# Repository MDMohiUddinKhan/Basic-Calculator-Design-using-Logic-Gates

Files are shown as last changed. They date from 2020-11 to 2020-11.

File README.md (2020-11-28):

# Basic-Calculator-Design-using-Logic-Gates
I've designed Adder (4bit), Subtractor (4bit), Multiplier (2bit), Divisor (1bit) unit of basic BCD Calculator using Proteus Software; designed their PCB layout & had done Hardware Implementation.

# Adder-Subtractor unit:
UniConverter_20201128140115

# Multiplier unit:
UniConverter_20201128140604

# Divider unit:
UniConverter_20201128141047

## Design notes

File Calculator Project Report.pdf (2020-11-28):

# Islamic University of Technology (IUT)

## Organization of Islamic Cooperation (OIC)

## Department of Electrical and Electronic Engineering (EEE)

### Report Submission Date: 21st May, 2018

Course: EEE 4308 (Digital Electronics Lab)

Experiment Name: Basic Calculator Design using Logic Gates.

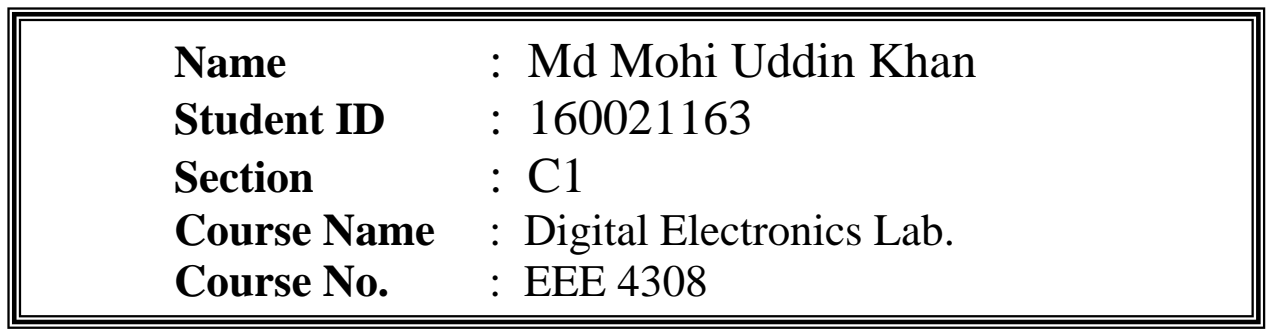
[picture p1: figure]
Name; : Md Mohi Uddin Khan; Student ID; Section; Course Name : Digital Electronics Lab.; Course No.; : EEE 4308

## INTRODUCTION:

The project to be submitted is a simple calculator using only logic gates. For this, I designed some separate units for different action. They are:
1. Adder Subtractor unit
2. Multiplier unit
3. Divider unit
4. Input keyboard unit
5. Memory unit
6. Display unit

## Adder-Subtractor Unit

In this unit the operations of addition and subtraction of single digit (4 bit Binary) decimal number, I used 2 Full Adders, 2 XOR gate IC, 1 Not gate IC, 1 AND gate IC, 1 OR gate IC. These are 1st logically derived in my note book.

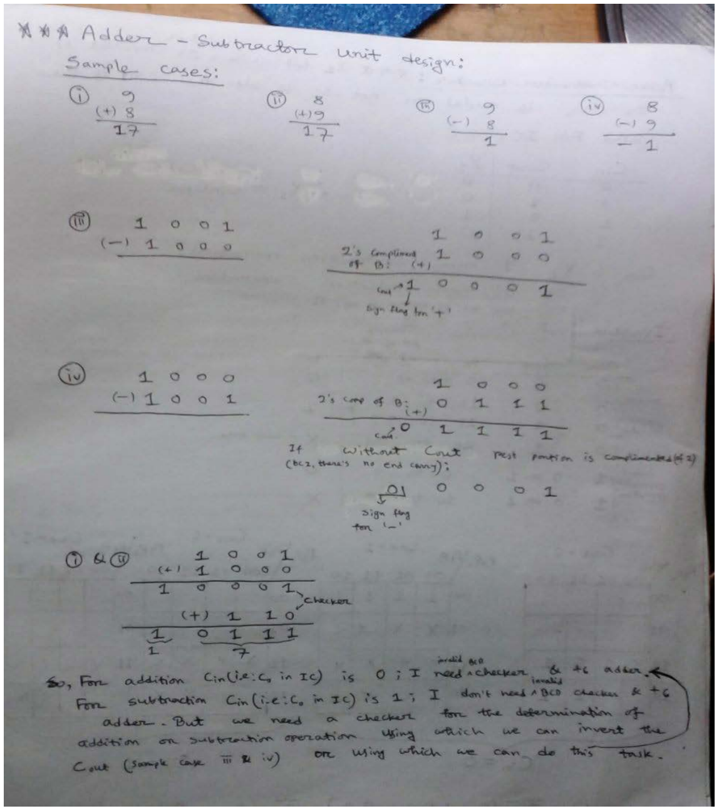
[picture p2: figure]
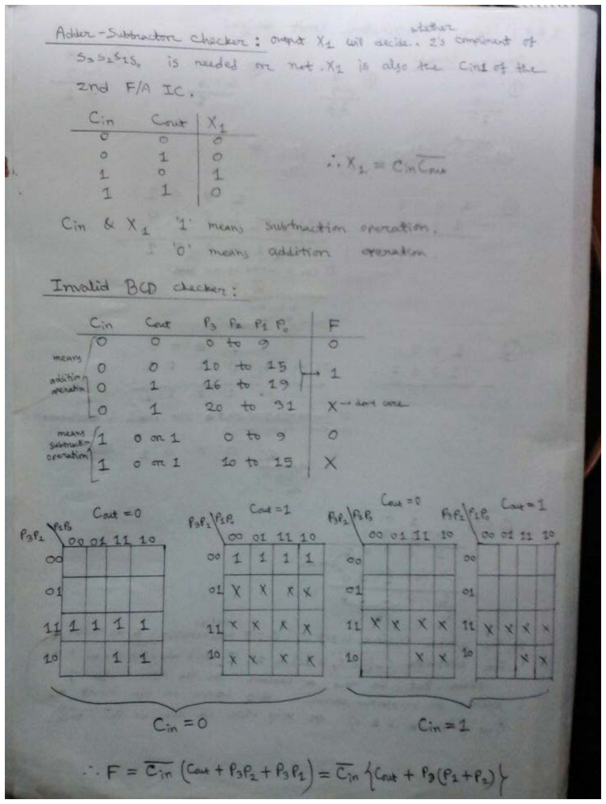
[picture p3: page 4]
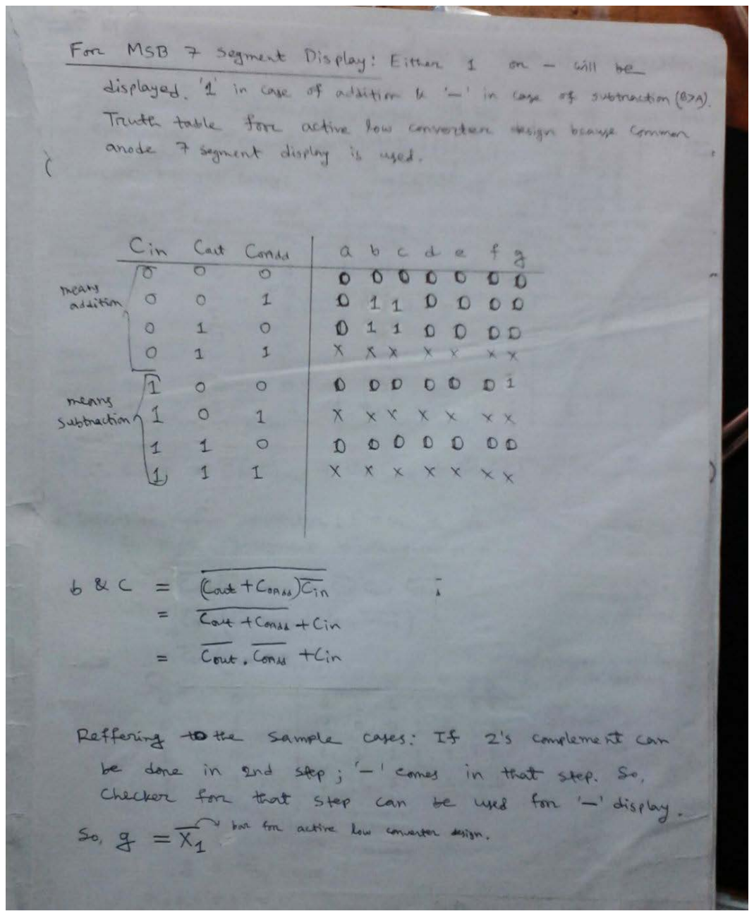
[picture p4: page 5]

Then these were implemented in Proteus 8.

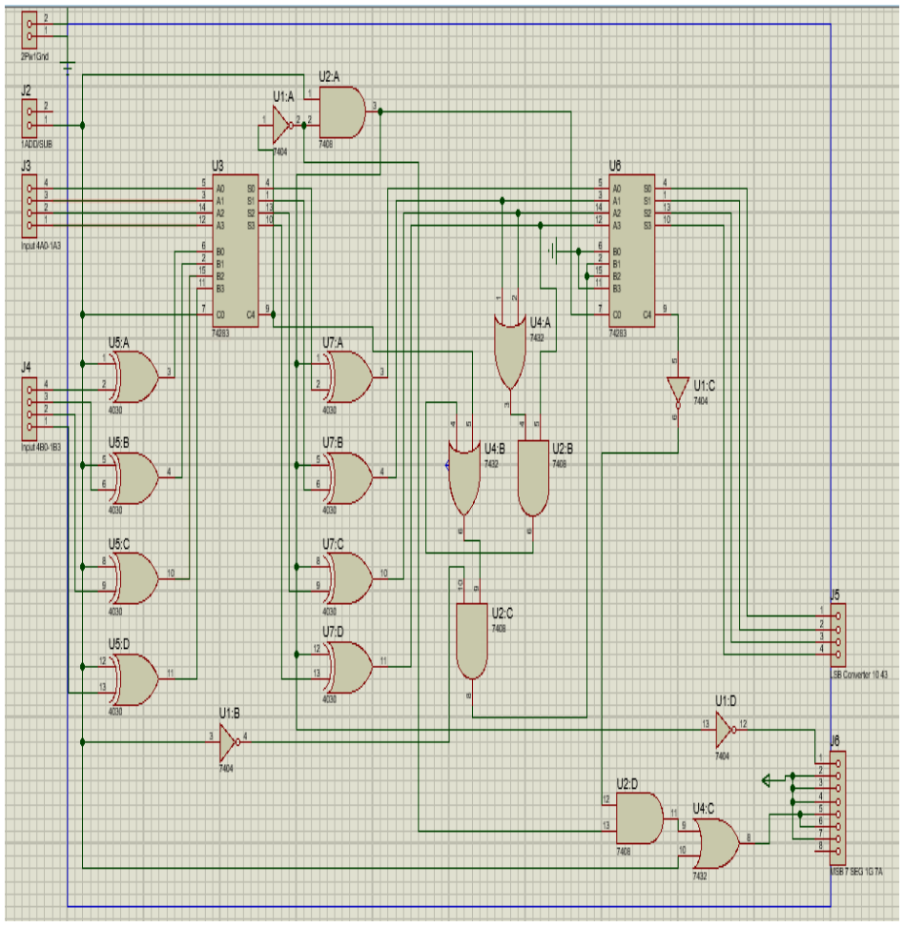
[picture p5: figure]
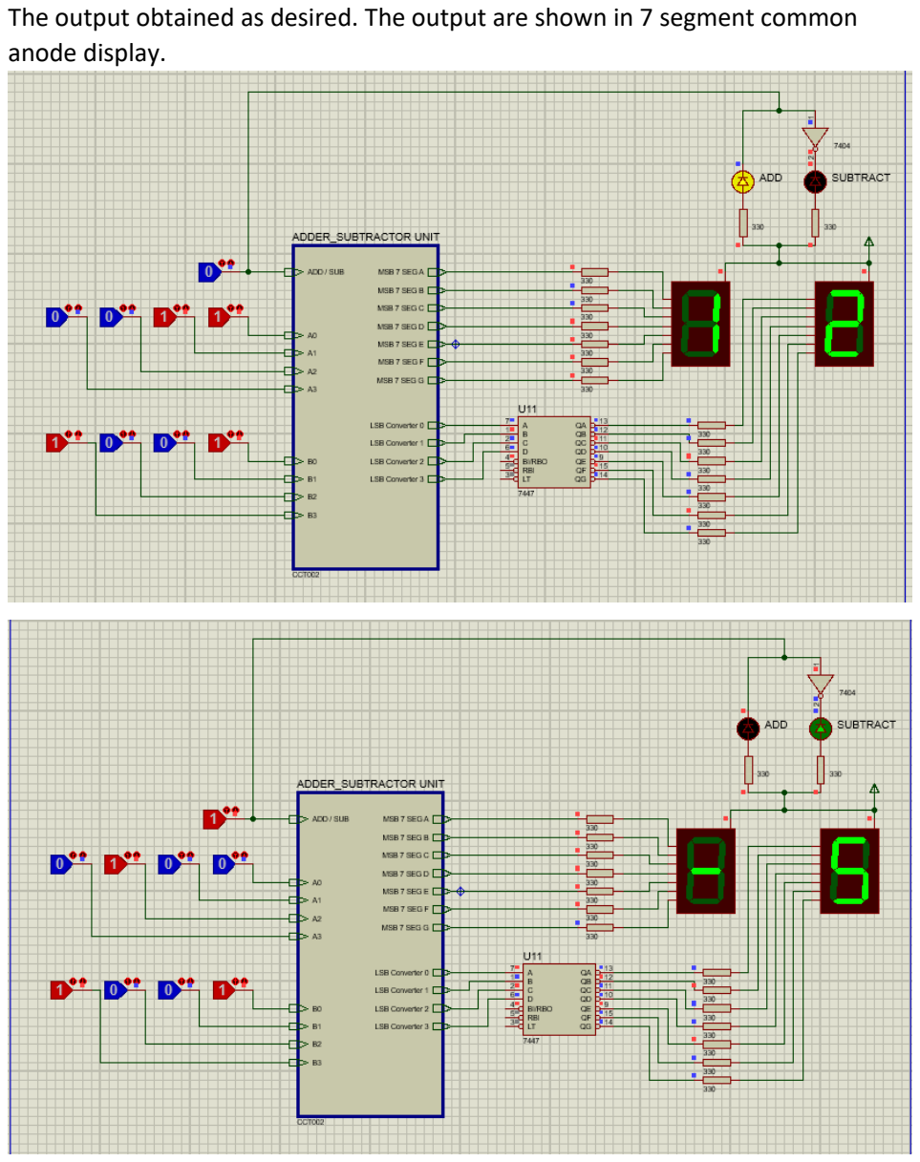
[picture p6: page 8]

The output obtained as desired. The output are shown in 7 segment common anode display.

Then, I had done the PCB design. Here 1st I had to make slight changes to our design by adding terminal blocks instead of logic-states and logic-probes. Then this was used to design the final PCB layout. I processed the PCB to be double layered. So the remaining connections had to be done.

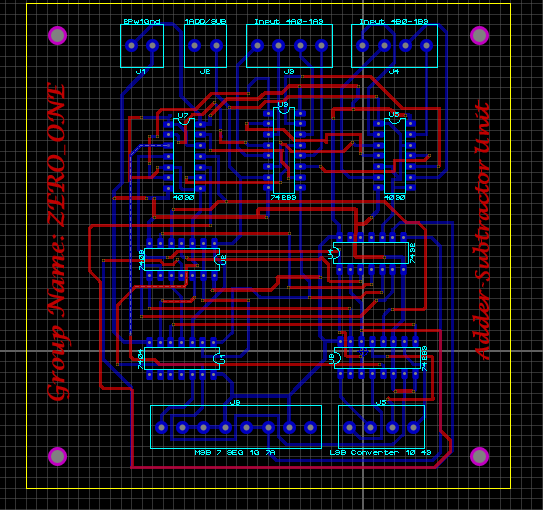
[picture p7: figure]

Finally the PCB design was completed. And the 3D design along with the original PCB in given below:

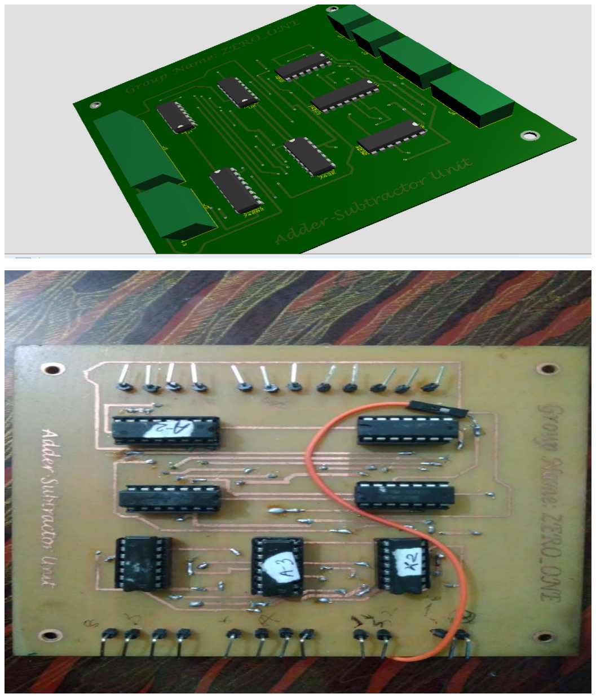
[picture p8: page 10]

## Multiplier:

In this unit the operations of addition and subtraction of single digit, 4 bit decimal number. Here I used 7 AND gate IC, 8 full adders, 3 OR gate IC and an Encoder. Then as before the steps are performed
1st the written rough calculations:

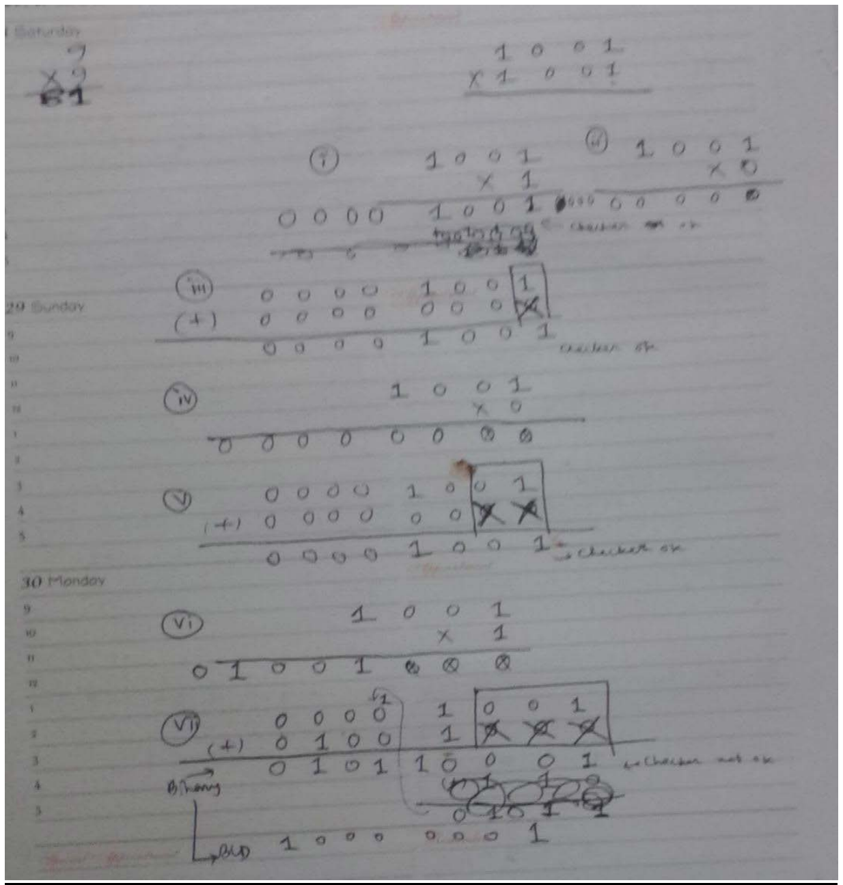
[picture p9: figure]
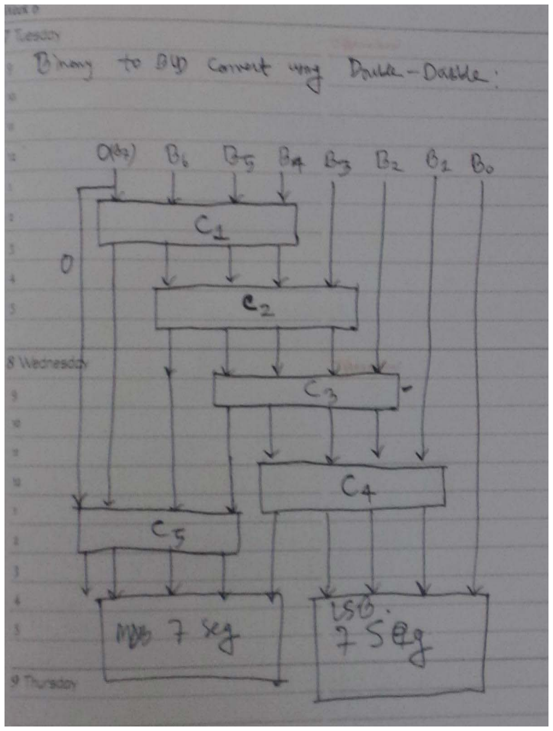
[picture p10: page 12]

Then the proteus Implementation:

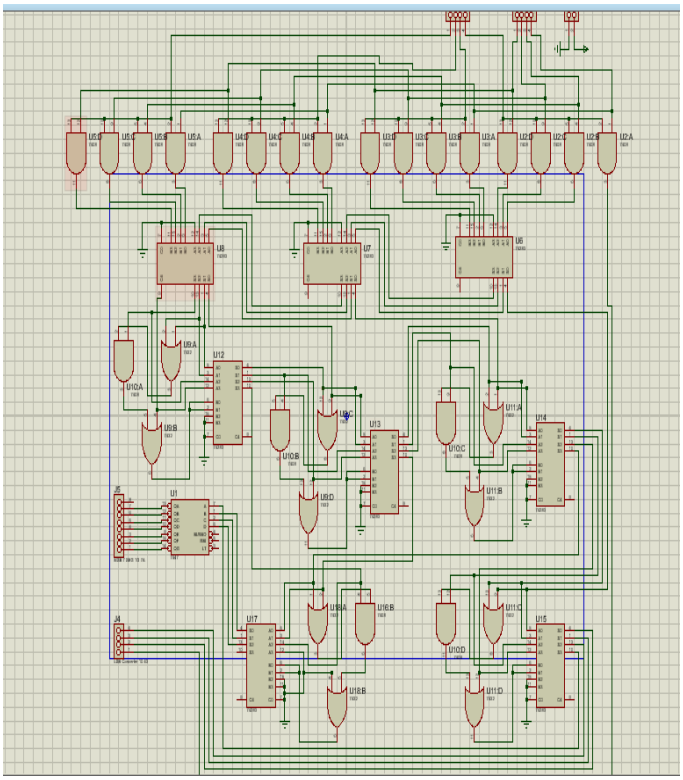
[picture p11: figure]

The outputs are checked and obtained as desired:

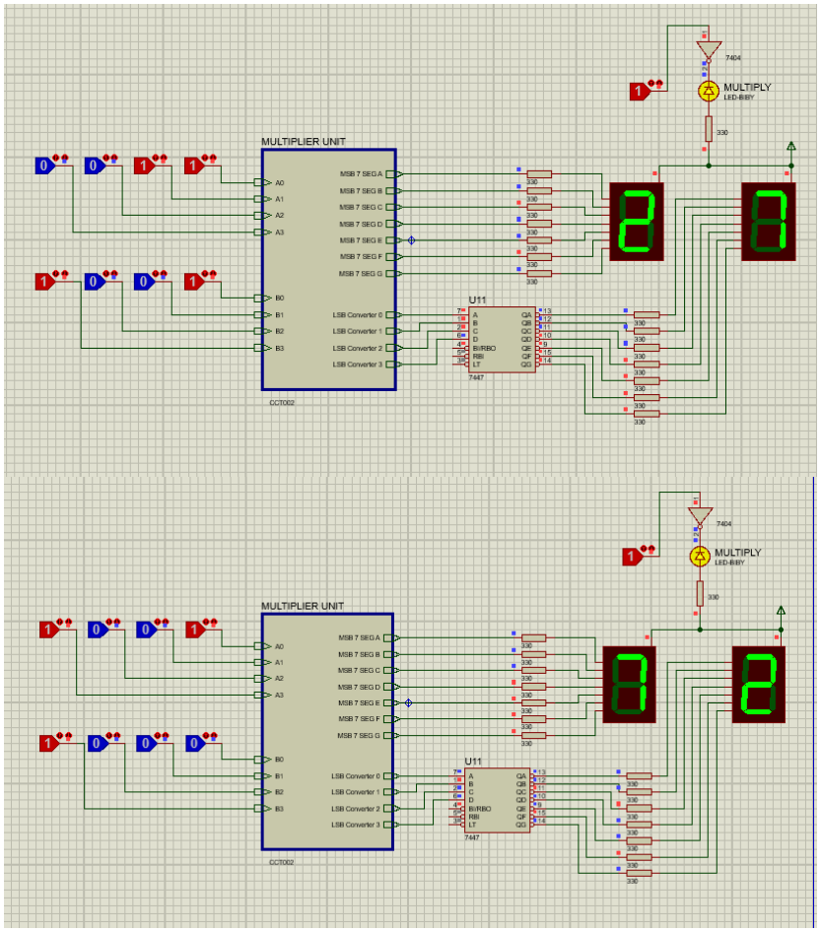
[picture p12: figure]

Then after adding the terminal blocks the PCB design was made and printed:

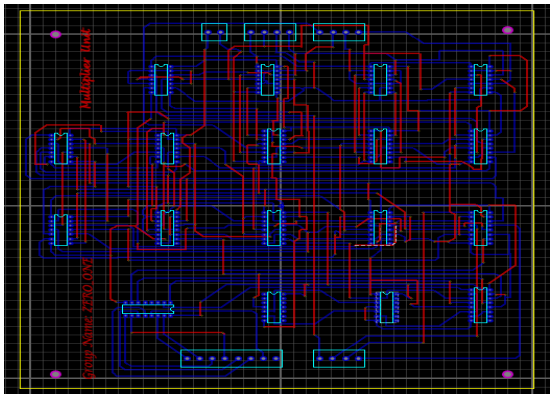
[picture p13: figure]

## Divider Unit

In this unit of the Division operation single digit (4 bit binary) decimal number is divided by another single digit Decimal number. But in this particular divider, the decimal places (i.e. Remainders) are not shown. Only the integer will be displayed. Here I used a total of 18 ICs including 9 Full adders, 4 Inverter IC, 2 OR gate IC, 2 AND gate IC and an 10 to 4 line Encoder.
As before the logical calculations and designs are done by hand calculation.

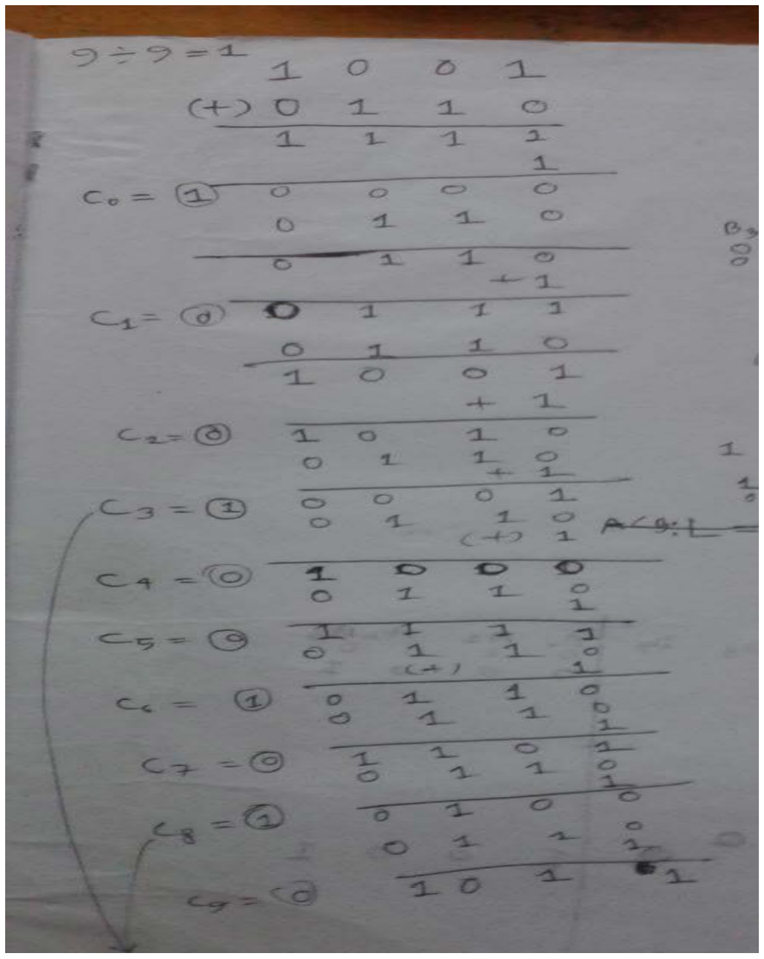
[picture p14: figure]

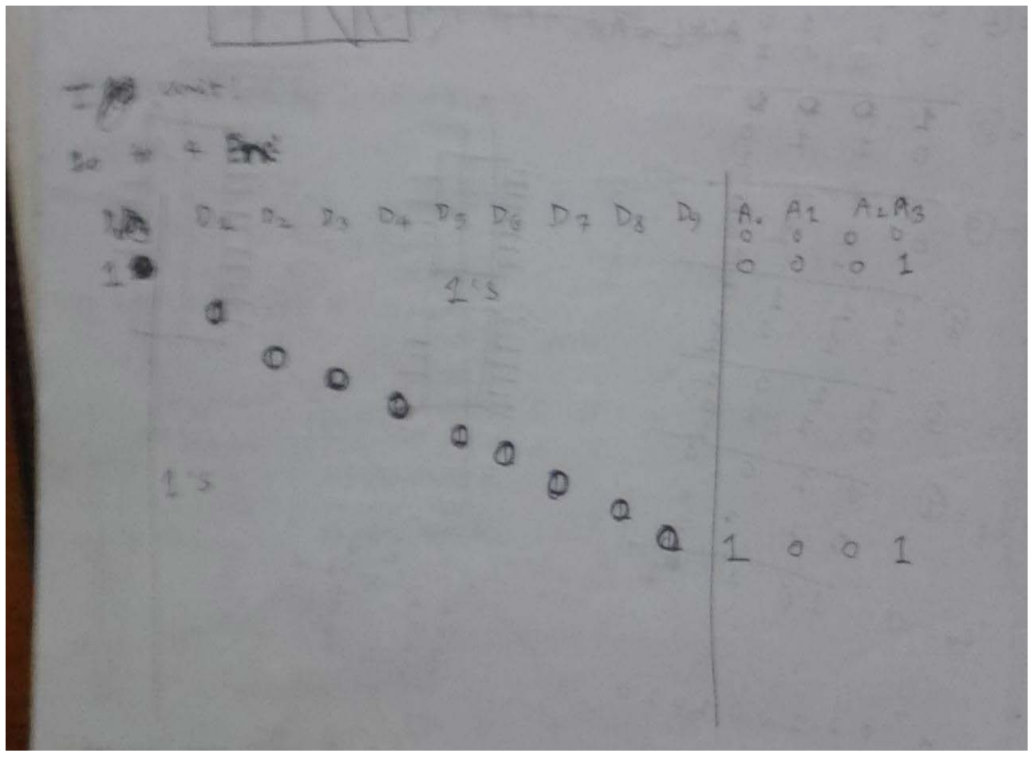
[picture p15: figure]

Truth table for 10 to 4 line Encoder used for summing up the required carry outs which is the quotient.

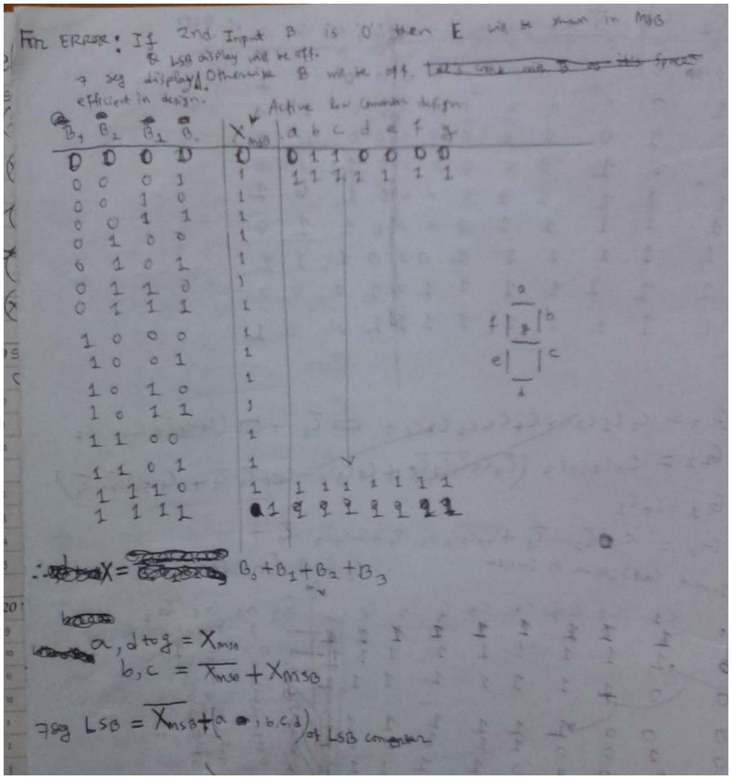
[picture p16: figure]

Truth table & Boolean Expression for Showing ‘E’ (Error) in case of any digit divided by zero.

Then done the Proteus Implementation and output generation.

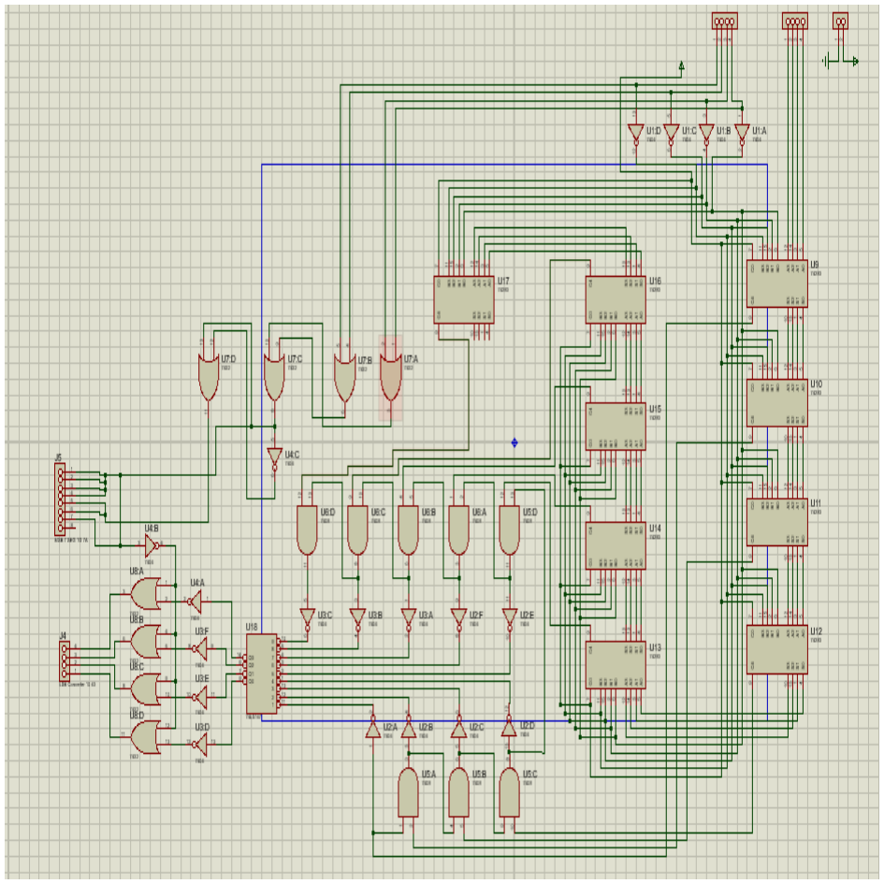
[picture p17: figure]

2nd input is subtracted 9 times from 1st input & successive differences. To make the undesired carry outs (if required subtraction is completed before 9th step) forcibly ‘0’ I used AND gates.
To make required carry outs suitable for using in 10 to 4 line decoder they are inverted using NOT gates.

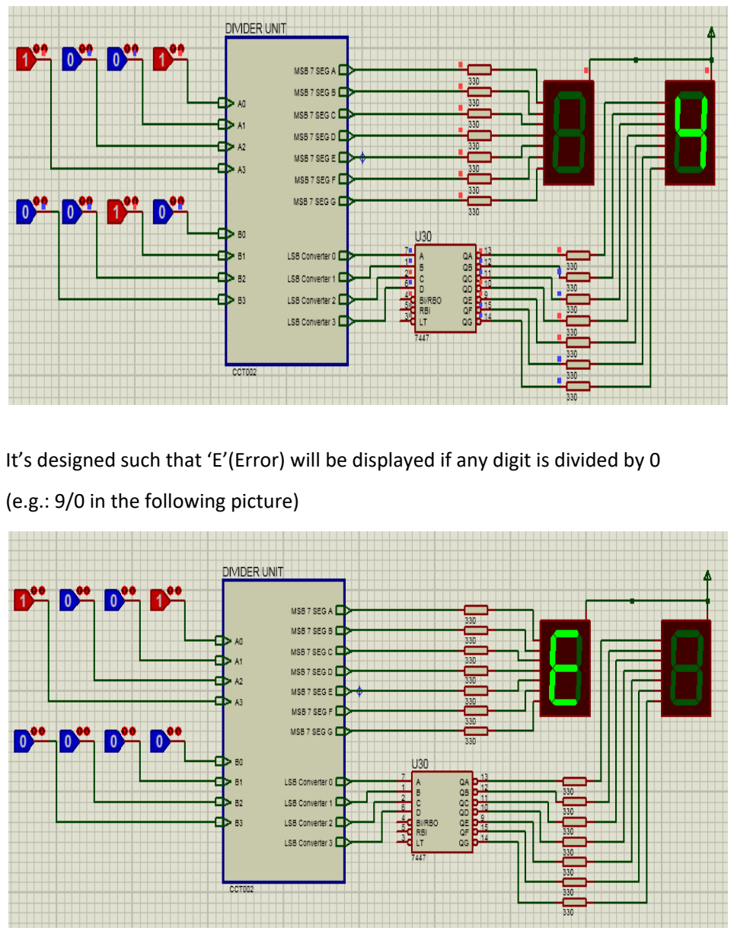
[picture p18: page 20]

It’s designed such that ‘E’(Error) will be displayed if any digit is divided by 0 (e.g.: 9/0 in the following picture)

And finally the PCB design was done. The design and PCB print is given below:

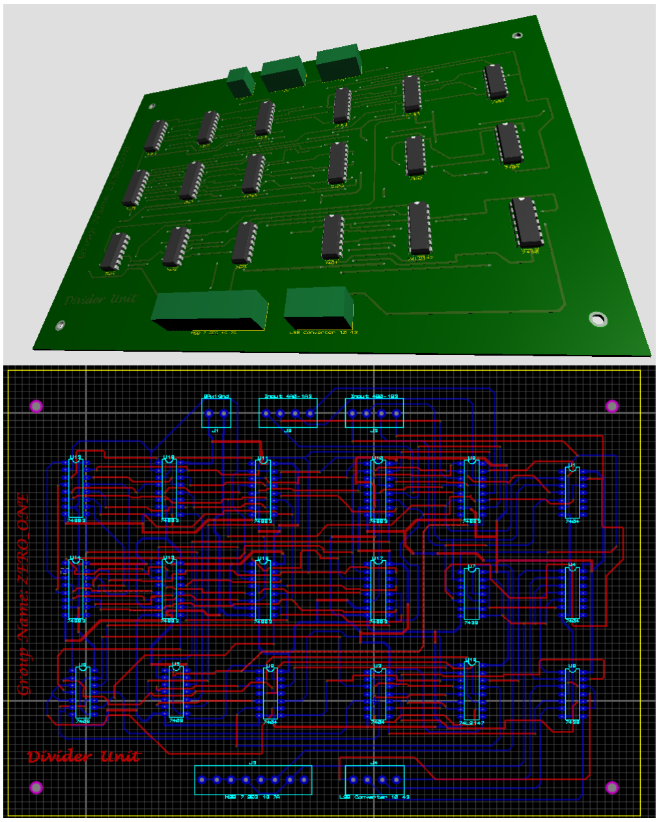
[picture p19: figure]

In case of adder-subtractor unit, I first implemented the circuit on breadboard and got the results in the form of binary outputs which Ire indicated by LEDs. LED on meant 1 and off meant 0.

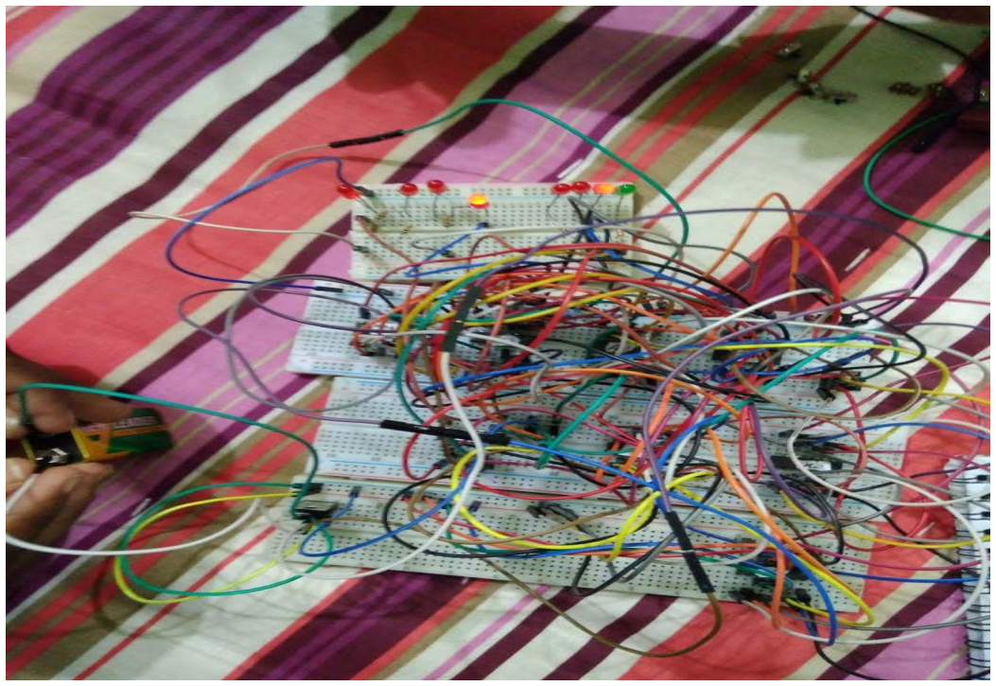
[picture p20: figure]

## Display Unit

The display unit consists of 2 common anode 7 segment single digit displays, BCD to 7 seg converts and power supply. When the outputs came to be 0, any desired segment would light up.

The output looked as below:

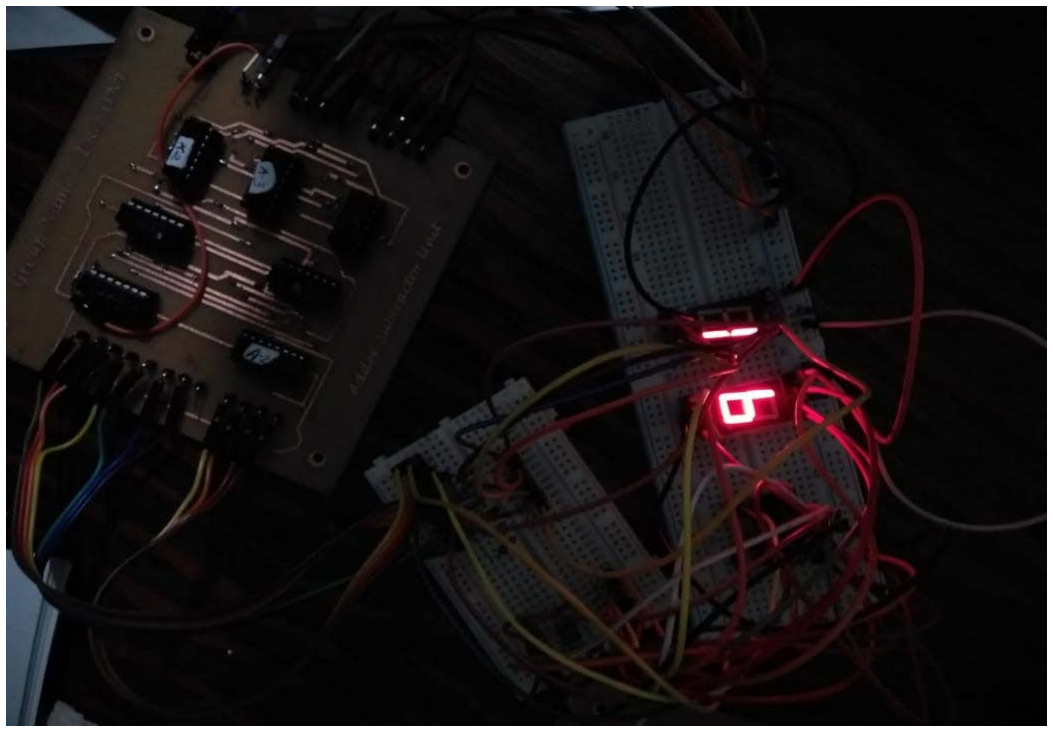
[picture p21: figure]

### COSTINGS

### The overall costing for buying the different components and accessories for the hardware implementation was BDT 3788 . And details of the costings are given below:

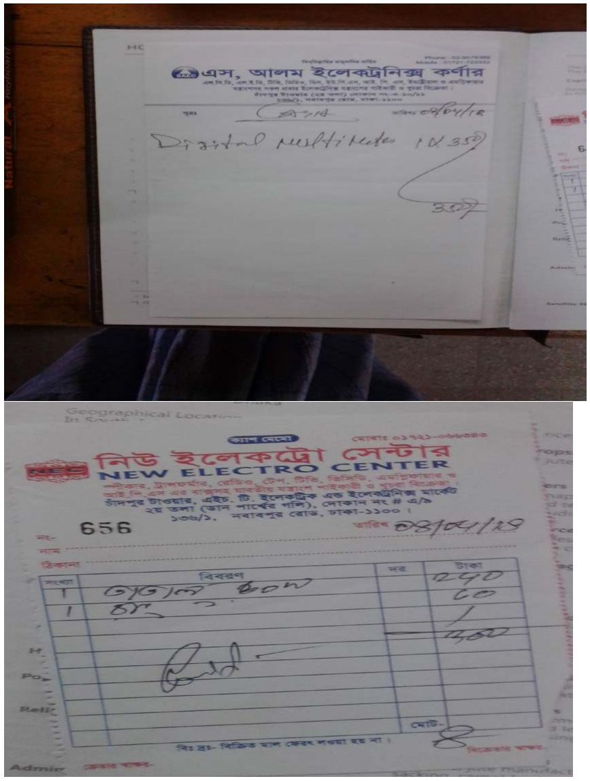
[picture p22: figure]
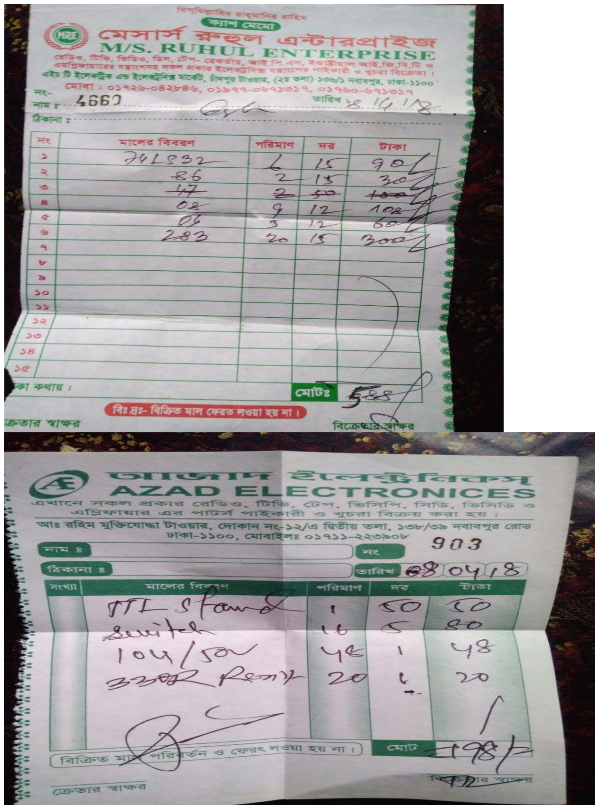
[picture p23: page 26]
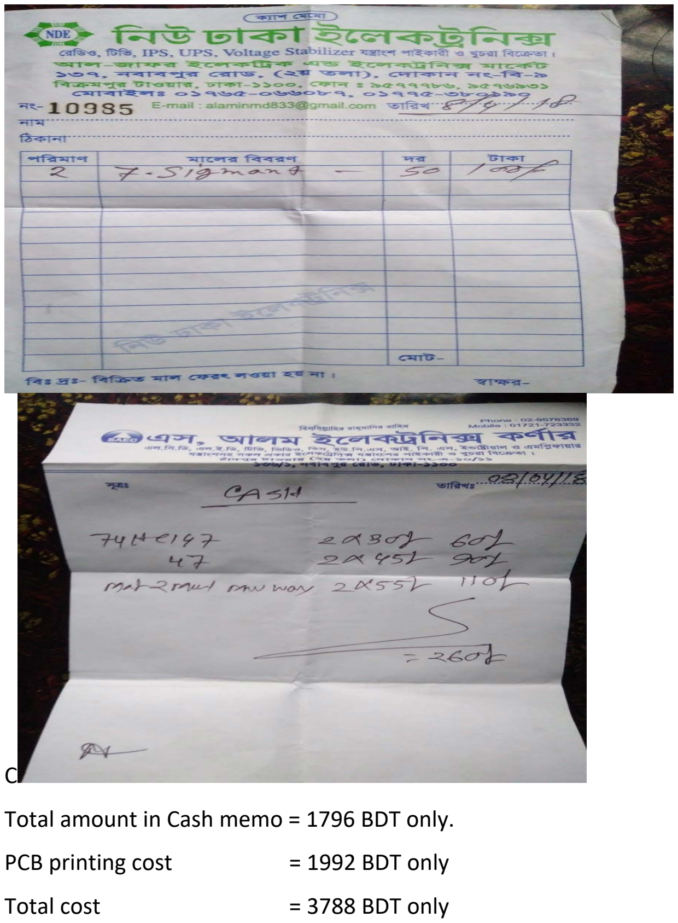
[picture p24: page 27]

C
Total amount in Cash memo = 1796 BDT only.
PCB printing cost | = 1992 BDT only
Total cost | = 3788 BDT only

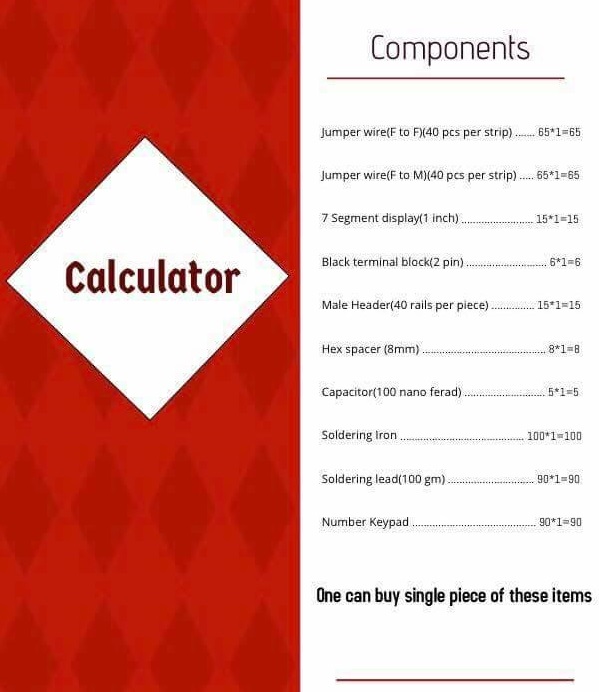
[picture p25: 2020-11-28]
IC hardware models 2.jpg

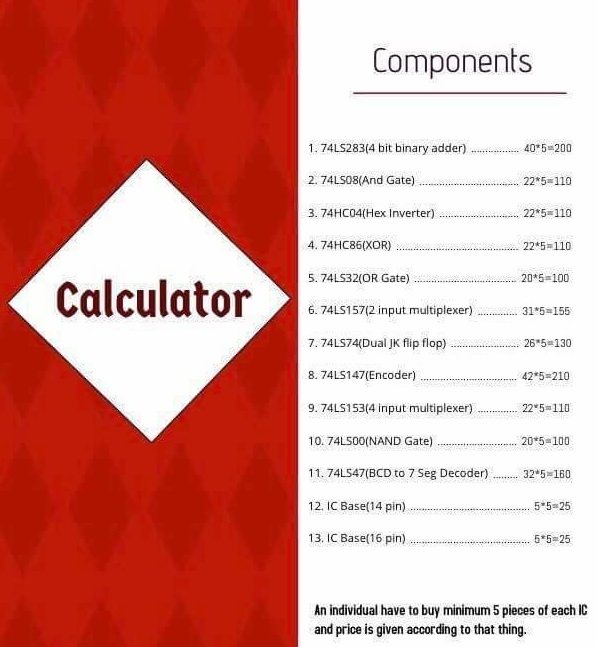
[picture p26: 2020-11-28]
IC hardware models 1.jpg

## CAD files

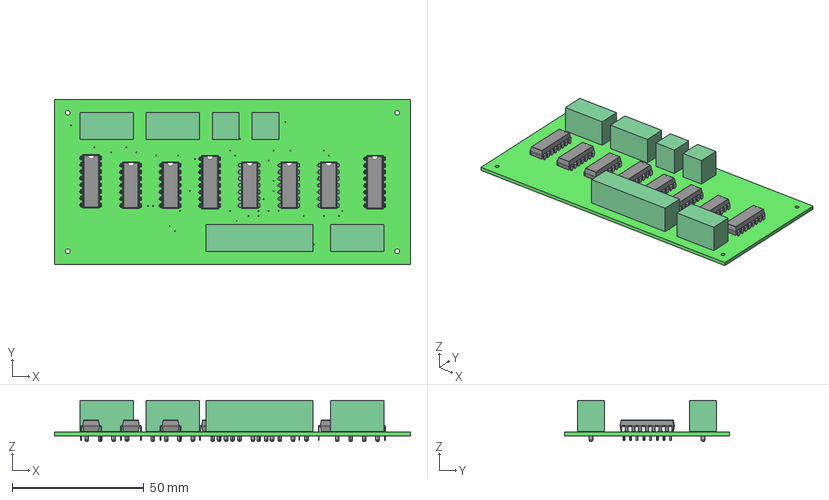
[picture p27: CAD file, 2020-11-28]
PCB design/Adder Subtractor unit PCB (Size_4.6 inch x 4.6 inch)/Adder Subtractor PCB.STEP
135.0 x 62.5 x 15.7 mm
Layer_1
Pin_1 x 6
Pin_2 x 6
Pin_3 x 4
Pin_4 x 4
Pin_5
Pin_6
Pin_7
Pin_8

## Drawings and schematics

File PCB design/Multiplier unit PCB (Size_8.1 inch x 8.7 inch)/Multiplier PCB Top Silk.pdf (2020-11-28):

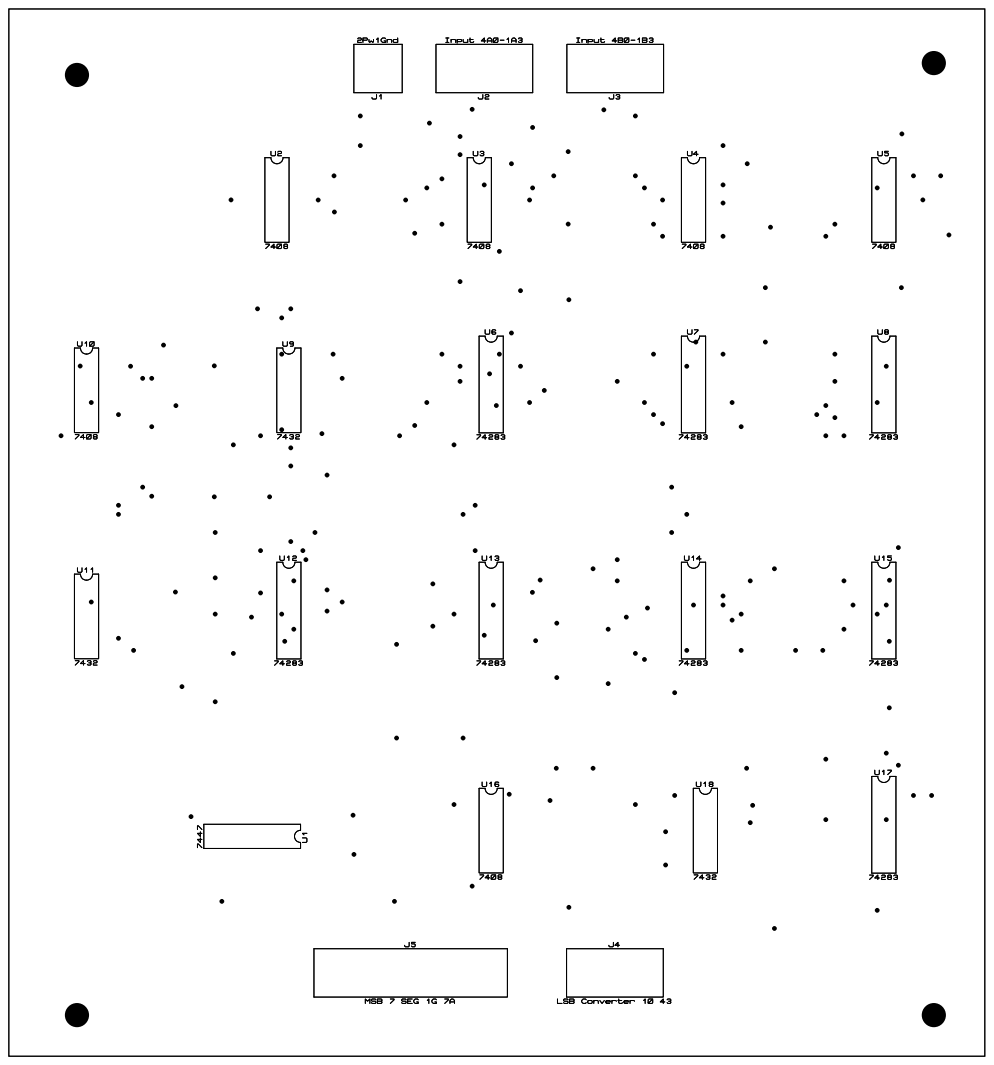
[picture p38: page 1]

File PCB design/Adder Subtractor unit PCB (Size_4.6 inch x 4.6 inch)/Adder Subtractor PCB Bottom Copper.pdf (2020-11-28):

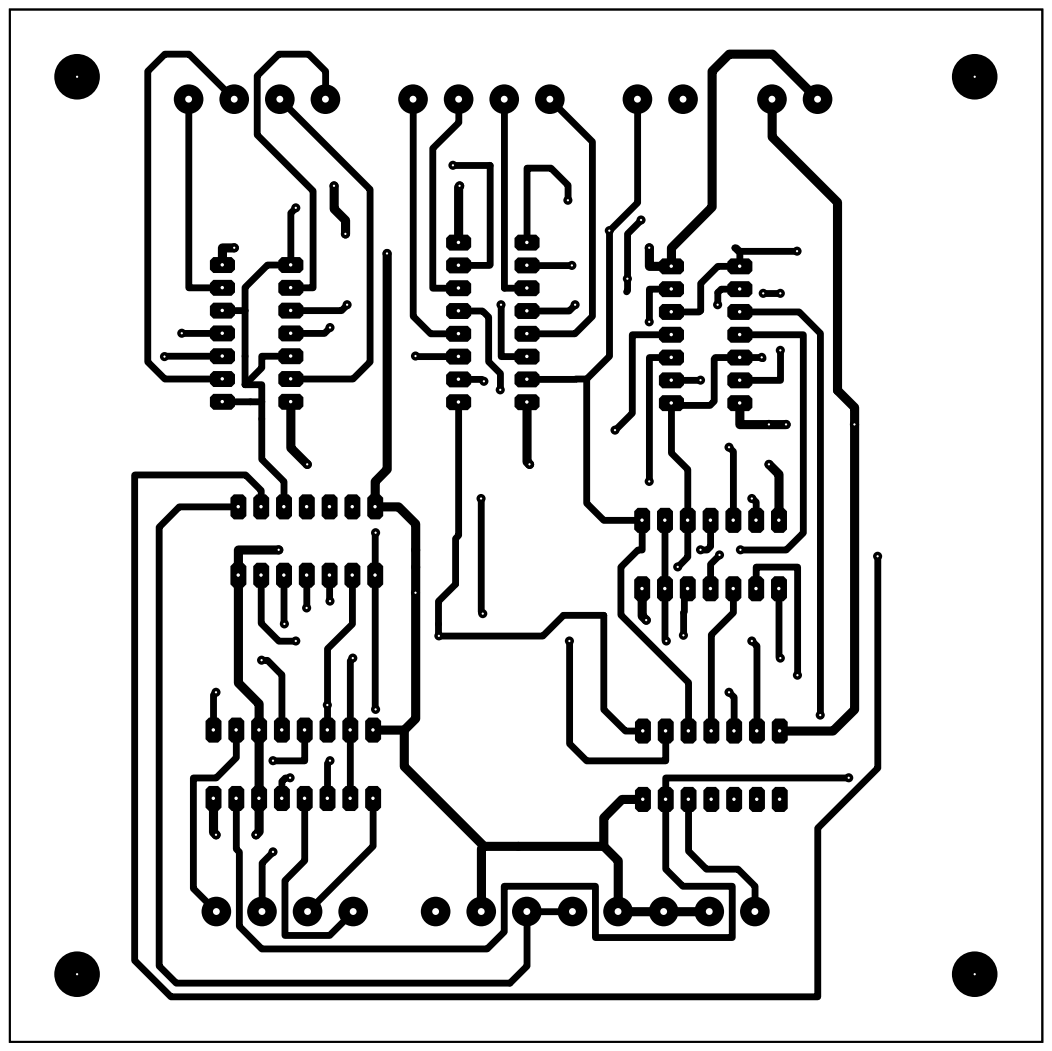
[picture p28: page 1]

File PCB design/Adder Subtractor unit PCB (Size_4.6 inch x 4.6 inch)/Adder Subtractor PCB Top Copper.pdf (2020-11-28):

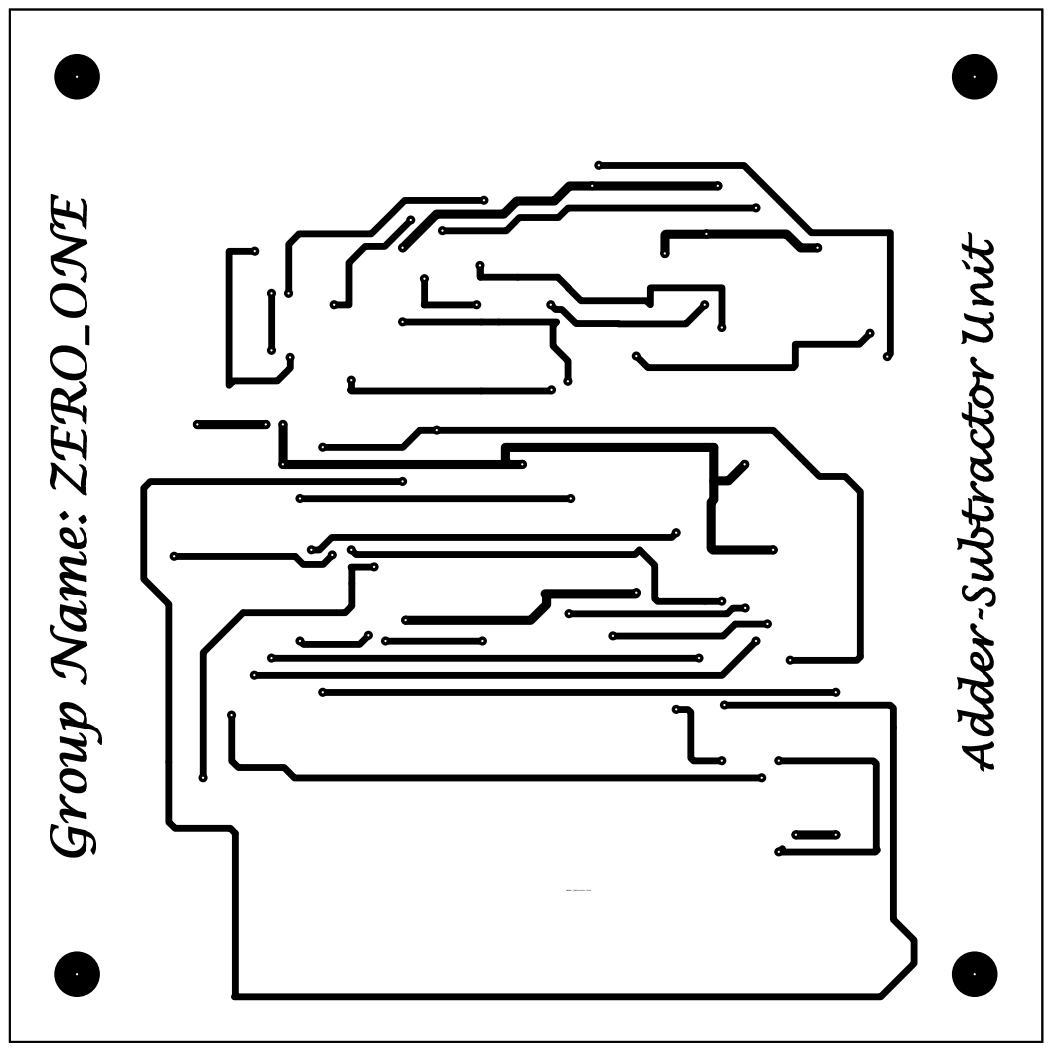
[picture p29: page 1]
Adder_Subtractor Unit

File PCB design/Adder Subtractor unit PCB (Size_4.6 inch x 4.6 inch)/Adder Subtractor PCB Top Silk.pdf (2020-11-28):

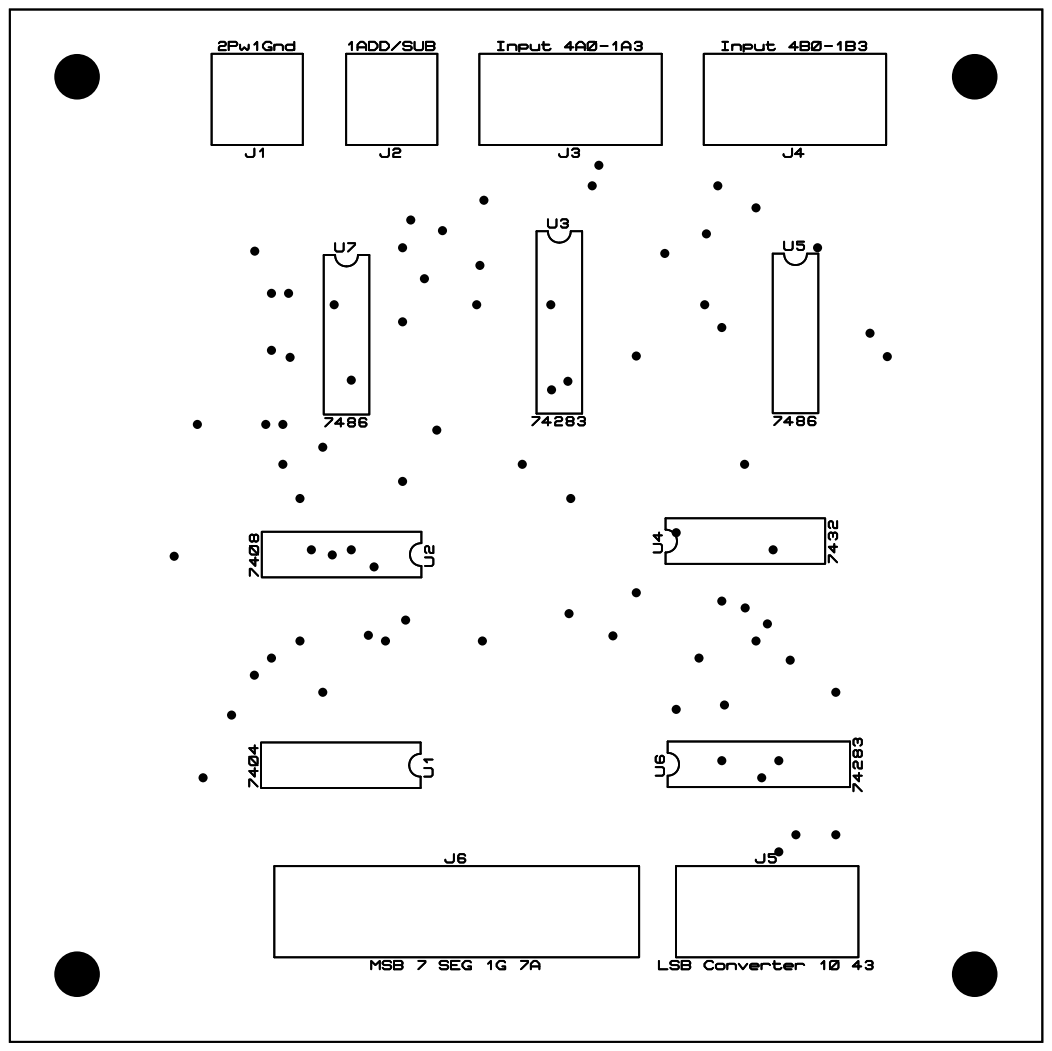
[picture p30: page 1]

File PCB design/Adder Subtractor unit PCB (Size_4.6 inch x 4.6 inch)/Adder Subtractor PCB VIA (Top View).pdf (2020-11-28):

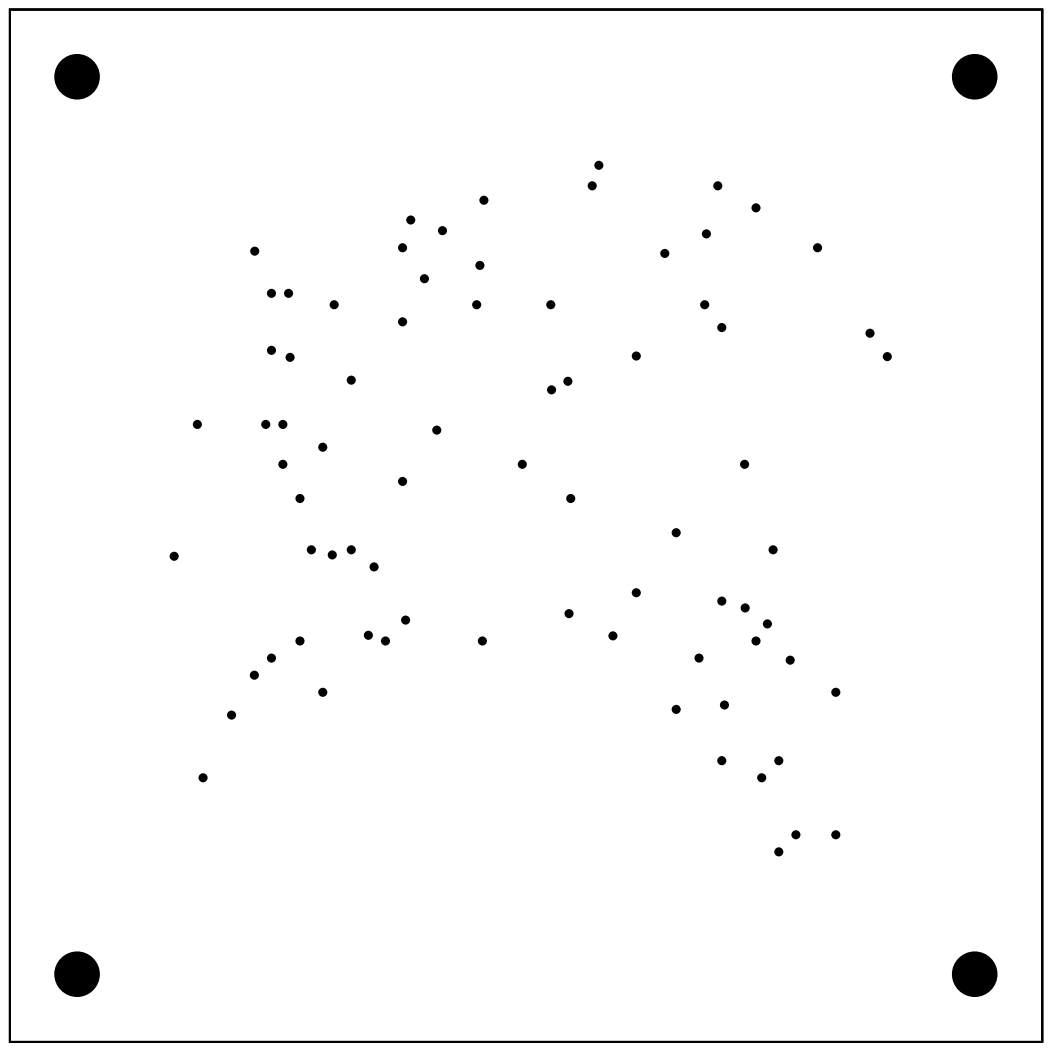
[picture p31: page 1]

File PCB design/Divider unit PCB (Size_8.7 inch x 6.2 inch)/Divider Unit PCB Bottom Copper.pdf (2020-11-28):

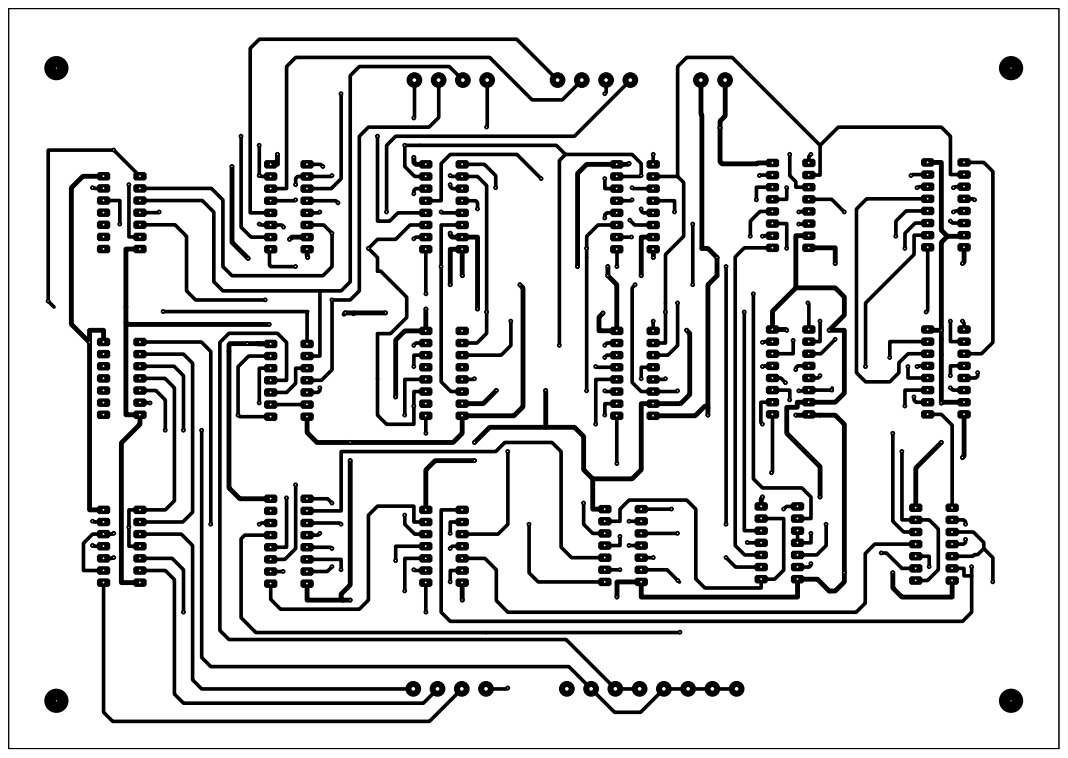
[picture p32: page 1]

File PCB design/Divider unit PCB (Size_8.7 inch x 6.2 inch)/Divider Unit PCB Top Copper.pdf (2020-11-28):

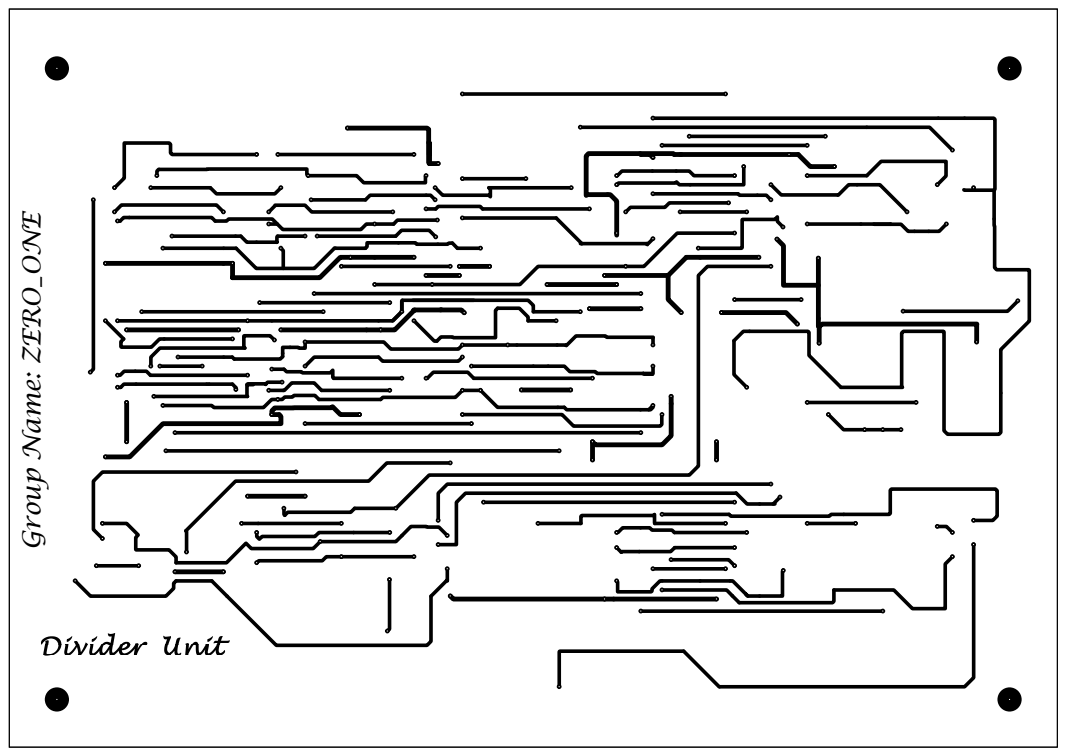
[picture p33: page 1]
Group Name: ZERO_ONE

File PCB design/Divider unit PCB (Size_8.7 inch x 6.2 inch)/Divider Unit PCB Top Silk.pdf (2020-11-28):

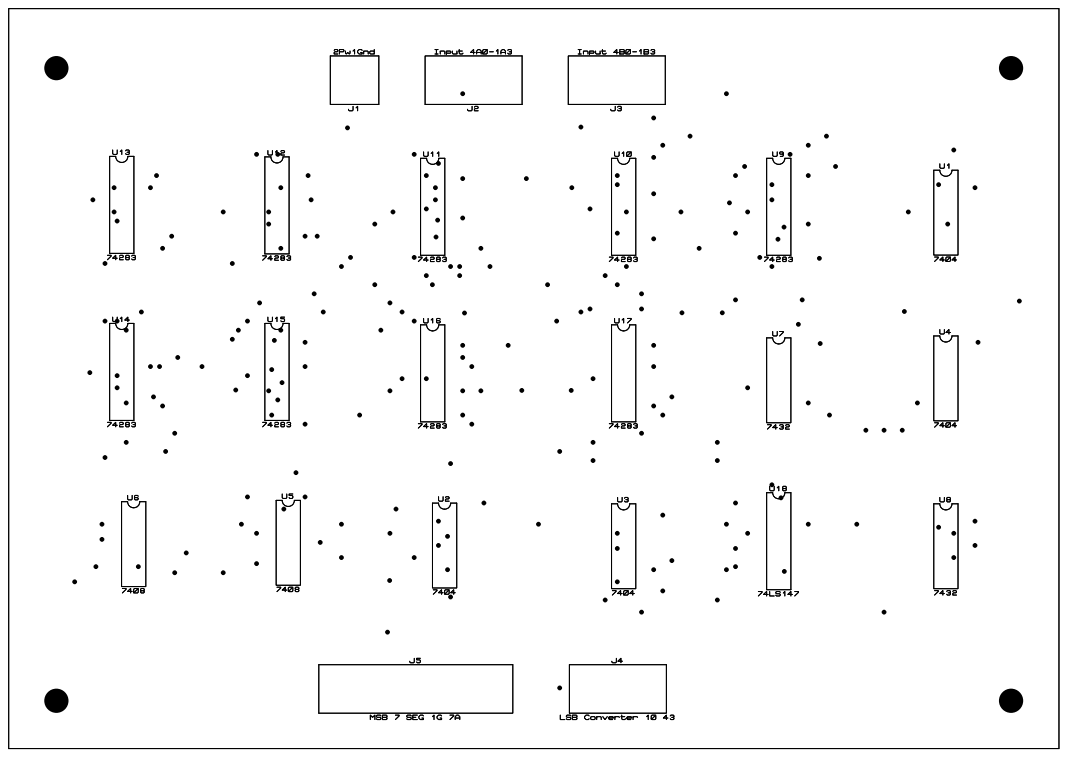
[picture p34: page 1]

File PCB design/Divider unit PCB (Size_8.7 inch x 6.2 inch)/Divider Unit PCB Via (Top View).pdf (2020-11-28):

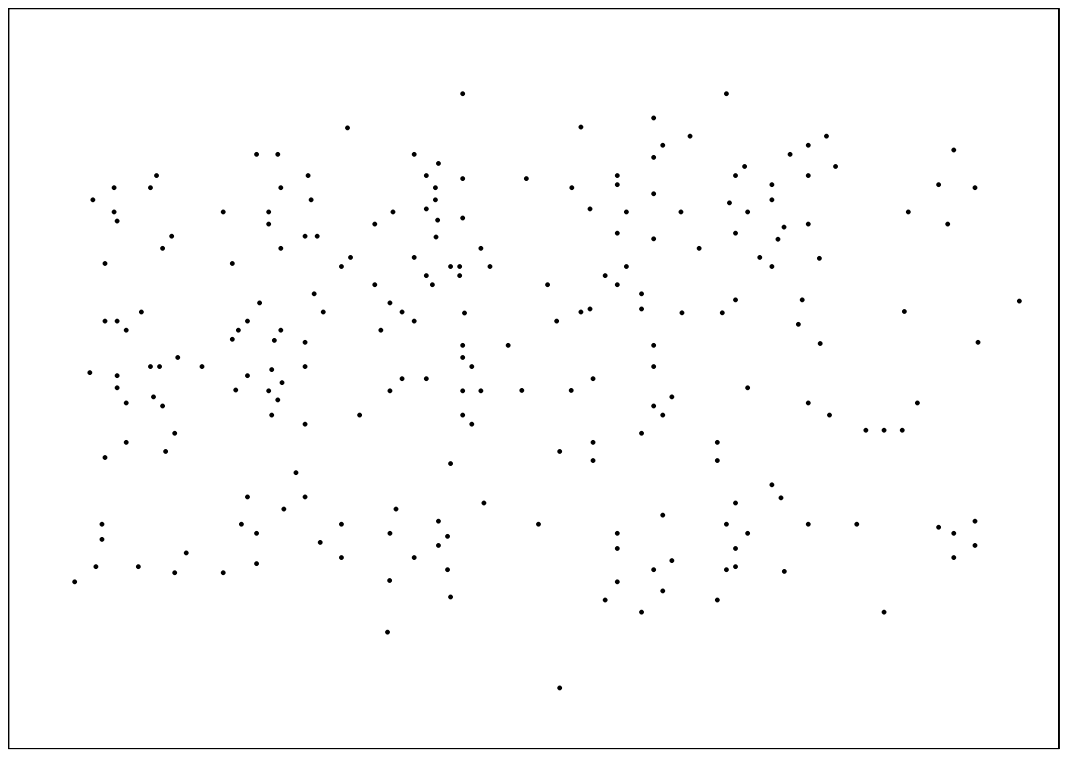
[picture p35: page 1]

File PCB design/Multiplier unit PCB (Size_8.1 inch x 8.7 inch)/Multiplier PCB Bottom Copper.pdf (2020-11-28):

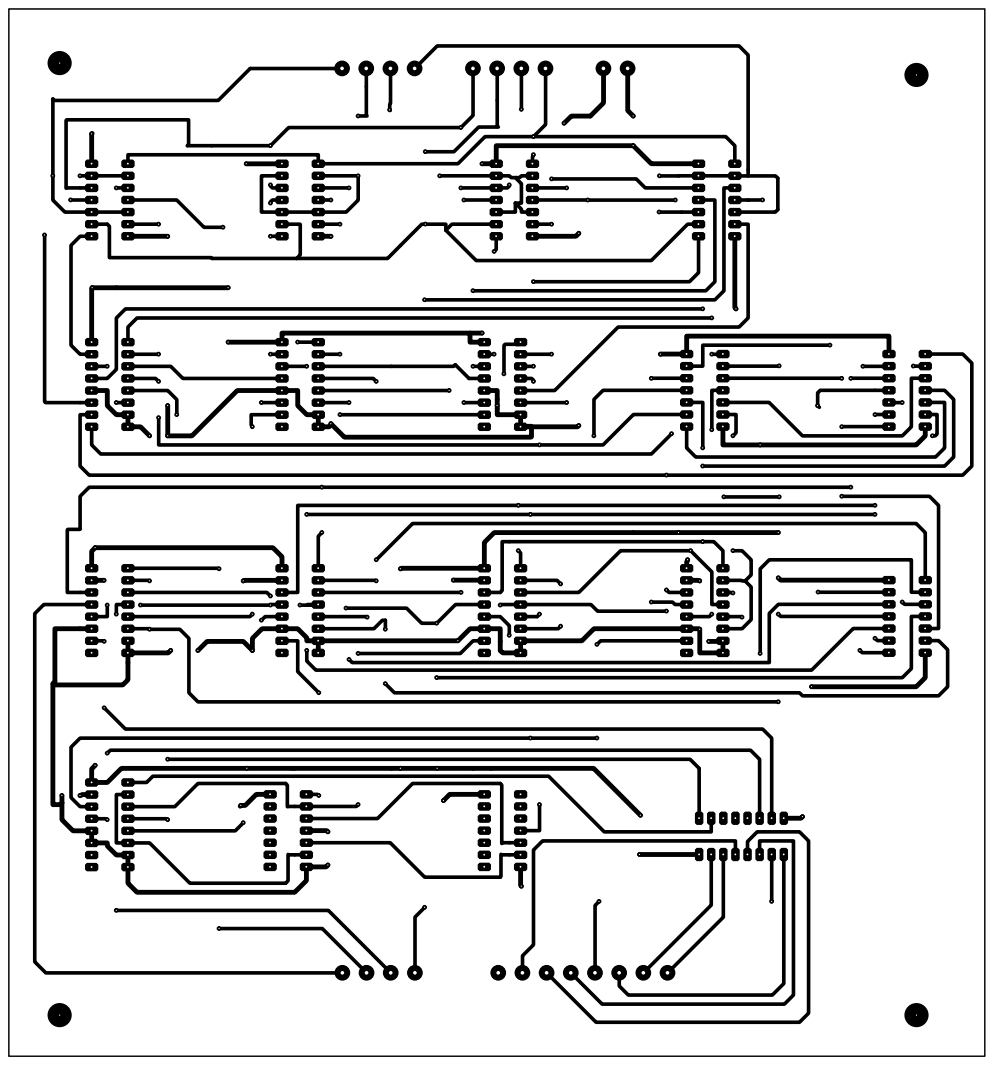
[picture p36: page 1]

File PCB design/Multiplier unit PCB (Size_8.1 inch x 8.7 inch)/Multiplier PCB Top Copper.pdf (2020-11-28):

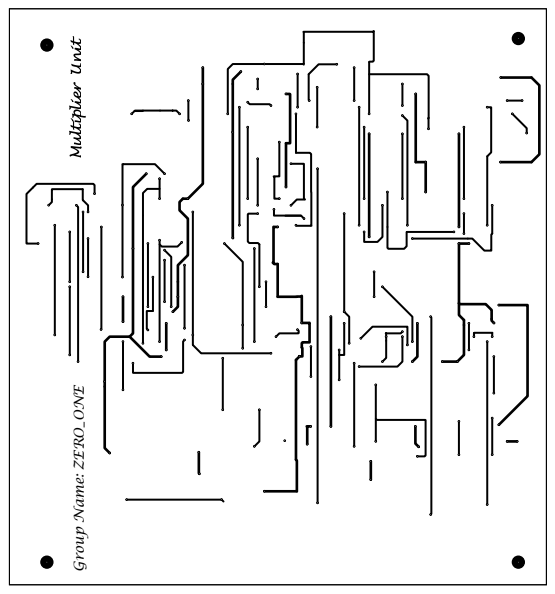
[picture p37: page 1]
Group Name: ZERO_ONE
